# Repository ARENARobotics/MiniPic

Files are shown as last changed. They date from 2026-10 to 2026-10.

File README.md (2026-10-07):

# MiniPic: Benchtop Vacuum Tweezers

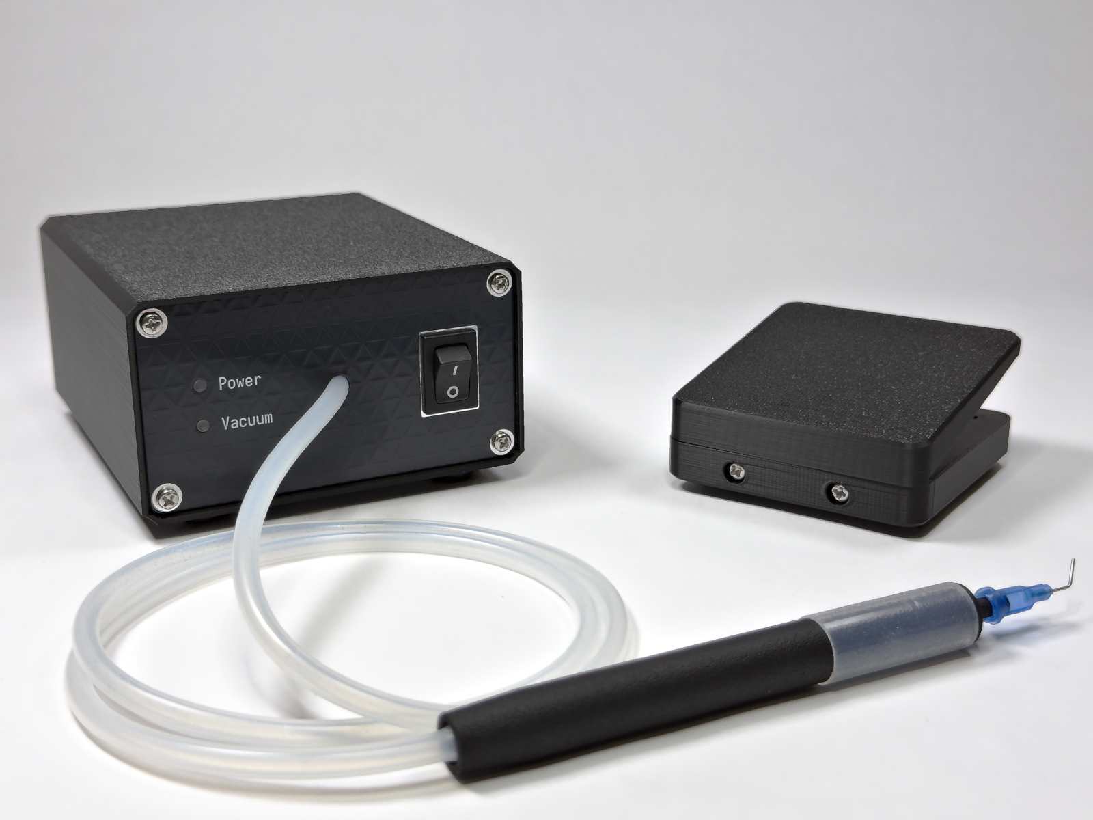
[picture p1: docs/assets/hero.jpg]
MiniPic Hero






Open-source vacuum tweezers built for repairability. Engineered for SMD soldering and precision rework, with a robust design adaptable to any application requiring controlled suction and handling of small parts.

---

### Features

* **Two operating modes:** foot pedal starts or stops the vacuum motor
* **Solenoid valve** for instant component release
* **Heat-resistant pen** rated up to **160°C**
* **Full set of precision needles and suction cups** for all sizes of SMD components
* Handles components down to **0201 (0.6 x 0.3mm)** and up to **100g**
* **Flexible silicone** vacuum tubing
* **MX hot-swap mechanical switch** in the foot pedal
* **Slip-resistant** rubber feet
* **Inline filter** to protect the vacuum motor
* **LED status indicator** for vacuum engagement

---

### Documentation & Source Files

* **[Assembly Manual](./docs/ASSEMBLY_MANUAL.pdf)** - Step-by-step kit assembly Instructions & quickstart guide
* **[BOM](./BOM.csv)** - Bill of materials including reference links for purchase
* **[Electronics Source](./electronics)** - KiCAD projects for PCBs
* **[CAD Exports](./cad/exports)** - CAD export files (step)
* **[CAD Source](./cad/source%20files)** - CAD source files (FreeCAD)

---

### Our Story

Last summer, we founded a company developing advanced electronics for robot combat competitions. We were inexperienced and didn’t understand the market so the project didn’t work out. Throughout the project, we spent a lot of time designing and assembling PCBs on a tight budget. Like many others, we found that tweezers were cumbersome tools for placing SMD components. The search for a better alternative led us to vacuum tweezers, tools designed to pick and place SMD components using controlled suction. The plan was to buy something off the shelf, but all of the products that were in our price range were not usable. On the other hand, the existing professional tools would have drained our bank account. We were stuck between cheap, low quality options and expensive industrial tools, most of which lacked all the features we were actually looking for.

Out of this frustration, one of our team members got to work, and in a few days, we had a functional tool that made assembly faster and easier than before. After using it ourselves, we realized we could provide a better alternative to others facing the same lack of options. Using our prototype as inspiration, we redesigned our vacuum tweezers from the ground up. Highly functional while still remaining simple and repairable.

See MiniPic in action at: [arenarobotics.store](https://arenarobotics.store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).

---

### Licensing

* **Hardware & CAD files (`/electronics`, `/cad`):** Licensed under [CERN-OHL-S-v2](LICENSE.md).
* **Documentation & Media (`/docs`):** Licensed under [CC BY-NC-ND 4.0](https://creativecommons.org/licenses/by-nc-nd/4.0/).
* **Branding & Trademarks:** "MiniPic" and "ARENA Robotics" are trademarks of ARENA Robotics LLC. All rights reserved.

--- 

*Designed & Built by ARENA Robotics.*

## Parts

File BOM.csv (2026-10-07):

Part Name | Supplier | Link | Notes | Quantity
Pen Body | JLC | https://jlc3dp.com/3d-printing-quote | Use STEP files from Github | 1
Pen Grip | Amazon | https://www.amazon.com/uxcell-Silicone-Flexible-Silicon-Transfer/dp/B07PNR73WW/ |  | 1
18g, 21g, 23g Needles | Amazon | https://www.amazon.com/Waltool-Dispensing-Assortment-Stainless-Applicator/dp/B0FK4SYRQT/ |  | 1
18g Metal Needles | Amazon | https://www.amazon.com/Pack-Blunt-Dispensing-Needles-8G-18G/dp/B07QS6TR4G/ |  | 1
Suction Cup 3mm | AliExpress | https://www.aliexpress.us/item/2251832630050891.html |  | 1
Suction Cup 5mm | AliExpress | https://www.aliexpress.us/item/2251832630050891.html |  | 1
Suction Cup 10mm | AliExpress | https://www.aliexpress.us/item/2251832630050891.html |  | 1
Silicone Tube | AliExpress | https://www.aliexpress.us/item/3256811498681916.html |  | 1
Aux Cable | AliExpress | https://www.aliexpress.us/item/3256812323425938.html |  | 1
Hinge | JLC | https://jlcmc.com/product/s/D04/DJRG/spring-butterfly-binge-taper-hole?k=DJRG-25&productModelNumber=DJRG-25 |  | 1
Vacuum Pump | AliExpress | https://www.adafruit.com/product/4699 |  | 1
Solenoid valve | Adafruit | https://www.adafruit.com/product/4663 |  | 1
Main PCB | JLC | https://jlcpcb.com/ | Use Gerber file from Github | 1
Back Panel | JLC | https://jlcpcb.com/ | Use Gerber file from Github | 1
Front Panel | JLC | https://jlcpcb.com/ | Use Gerber file from Github | 1
Power Switch | Digikey | https://www.digikey.com/en/products/detail/e-switch/RA11131121/2720267 |  | 1
Rubber Feet | Digikey | https://www.digikey.com/en/products/detail/keystone-electronics/720/61956 |  | 8
Screws | JLC | https://www.amazon.com/Phillips-Tapping-Screws-Stainless-Steel/dp/B0825N1L3Z/ |  | 39
Vibration dampaning | JLC | https://jlcmc.com/product/s/H02/HJDQ/cushioning-strip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 |  | 1
Electrical Components | Digikey | Custom | Can be found in KiCAD files | 1
Spring | JLC | https://jlcmc.com/product/s/A04/ATJS/compression-springs-outer-diameter-reference-l%C3%97(35~40)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 |  | 1
Keyswitch | Amazon | https://www.amazon.com/GATERON-Switches-Pre-lubed-Mechanical-Keyboard/dp/B0DRF928W5 |  | 1
Keyswitch Socket | Adafruit | https://www.adafruit.com/product/4958 |  | 1
Filter | AliExpress | https://www.aliexpress.us/item/3256812076290057.html |  | 1

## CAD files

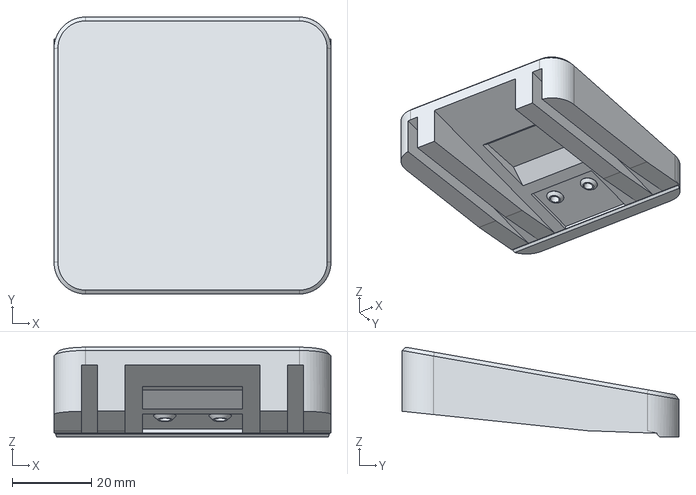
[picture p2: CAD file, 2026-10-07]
cad/exports/Foot Pedal - Top.step
70.0 x 70.0 x 22.6 mm

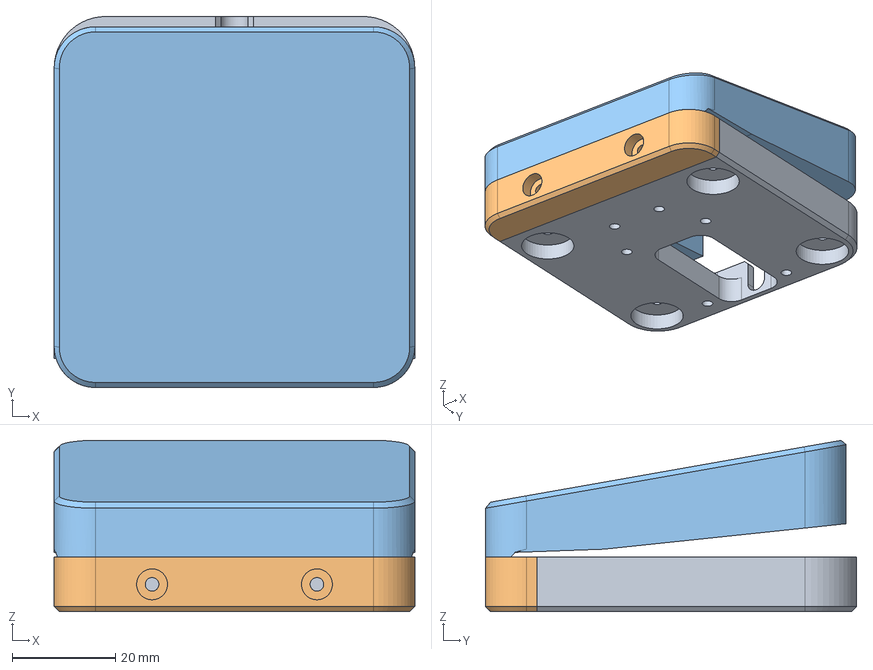
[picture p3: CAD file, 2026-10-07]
cad/source files/Foot Pedal.FCStd
70.0 x 72.0 x 33.2 mm
Base
Front
Top

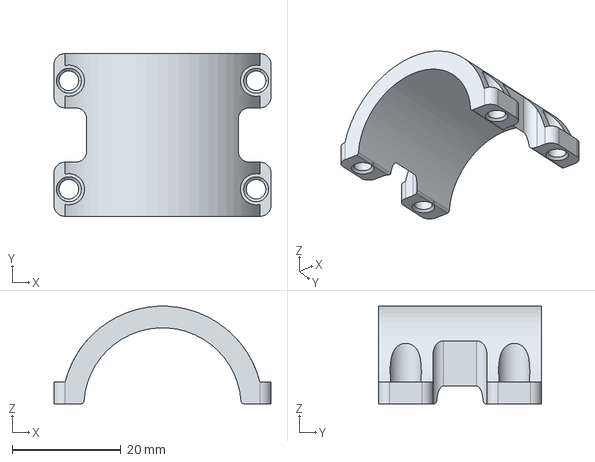
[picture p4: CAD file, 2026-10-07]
cad/exports/Base Station - Vacuum Cover.step
40.0 x 30.0 x 18.0 mm

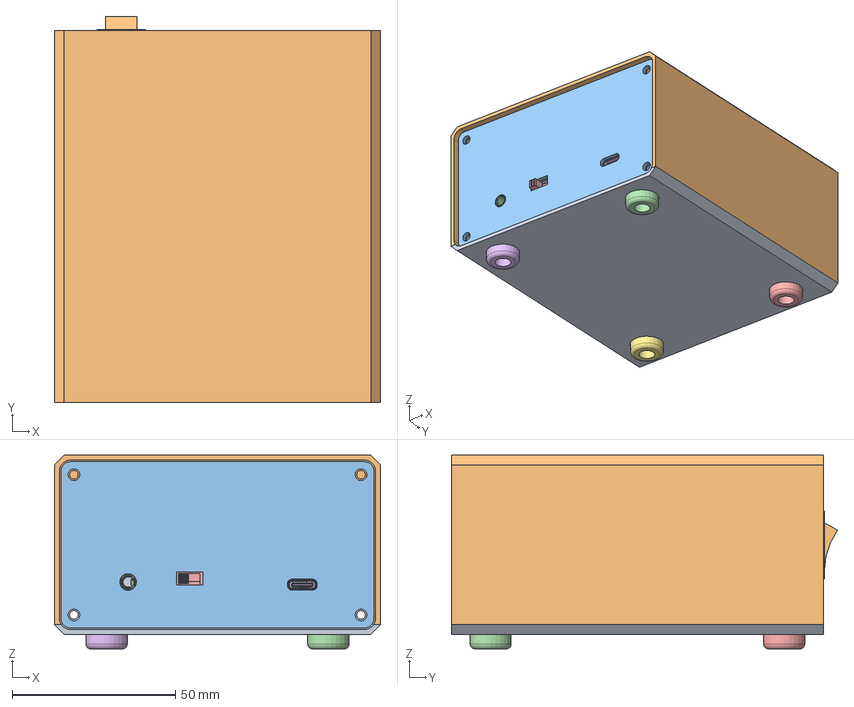
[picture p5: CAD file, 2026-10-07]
cad/source files/Base Station.FCStd
100.0 x 118.3 x 59.4 mm
Base
Cover
Back PCB
Foot 720 #001 x 2
Foot 720 #002 x 2
Foot 720 #003 x 2
Foot 720 #004 x 2
Vacuum Cover
Vacuum Motor v1
Power Switch001
Front Plate v0.1.0
Solenoid
Vaccum Tweezers_LED_holder_silkscreen
Vaccum Tweezers_LED_holder_PCB
LED Separator
Solenoid Cover
Light Pipe
Filter
Filter Cover
CUI_DEVICES_SJ-3523-SMT-TR001
Same_Sky_SLW-158562-5A-RA-N-D001
10164359-00011LF
Vaccum Tweezers_PCB

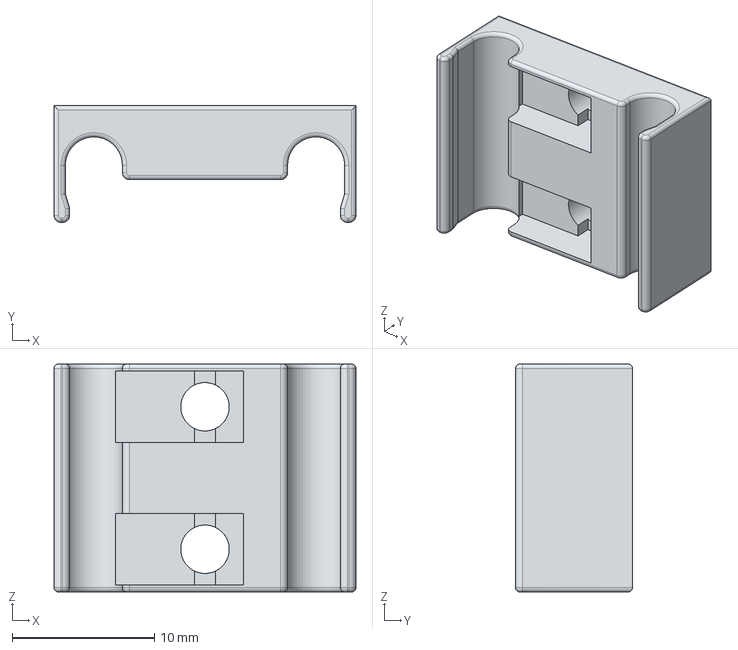
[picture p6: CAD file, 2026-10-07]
cad/exports/Base Station - LED Separator.step
21.2 x 8.20 x 16.0 mm

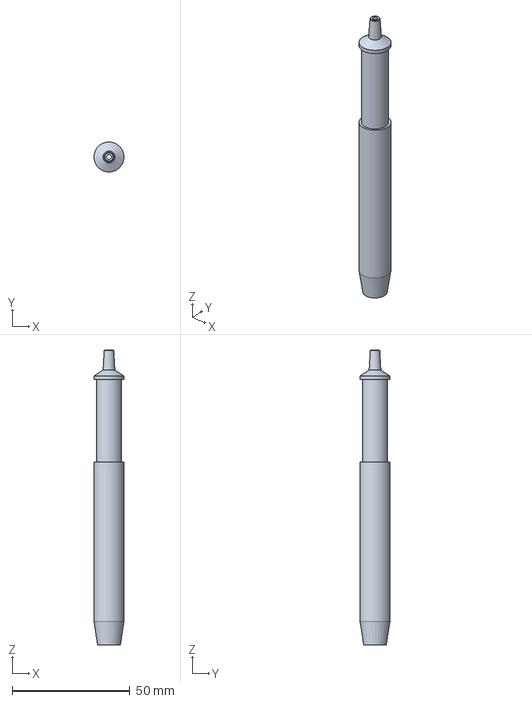
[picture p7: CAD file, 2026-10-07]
cad/source files/Pen.FCStd
12.7 x 12.7 x 125.0 mm

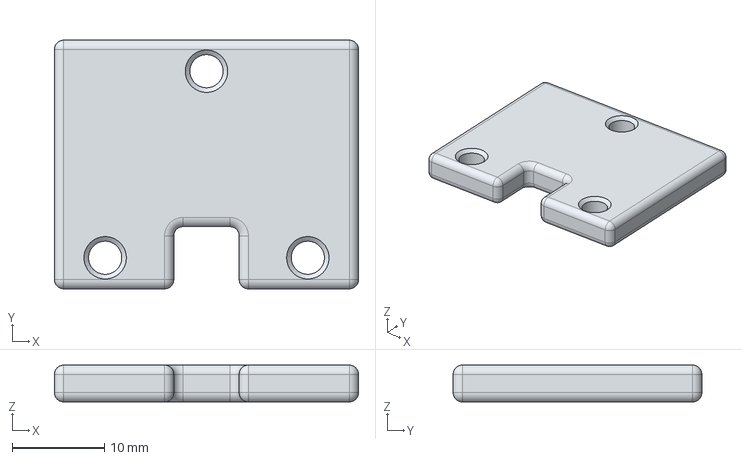
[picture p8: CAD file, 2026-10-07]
cad/exports/Base Station - Solenoid Cover.step
33.0 x 27.0 x 4.00 mm

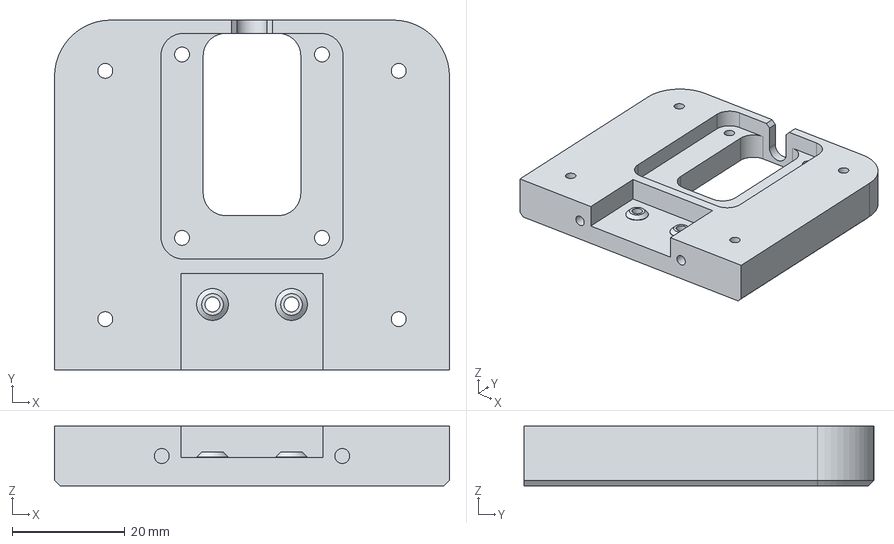
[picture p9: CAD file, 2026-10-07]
cad/exports/Foot Pedal - Base.step
70.0 x 62.0 x 10.6 mm

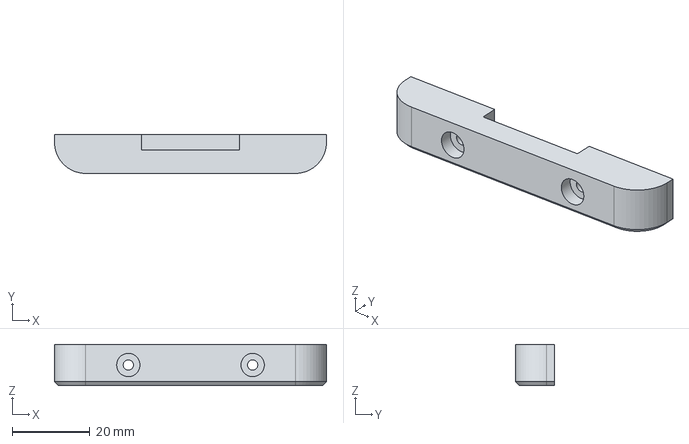
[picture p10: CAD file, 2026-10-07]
cad/exports/Foot Pedal - Front.step
70.0 x 10.0 x 10.6 mm

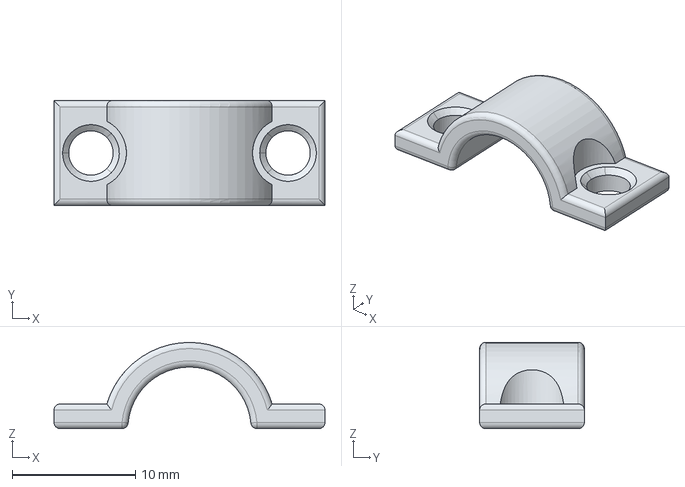
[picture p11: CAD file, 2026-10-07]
cad/exports/Base Station - Filter Cover.step
22.0 x 8.50 x 7.00 mm

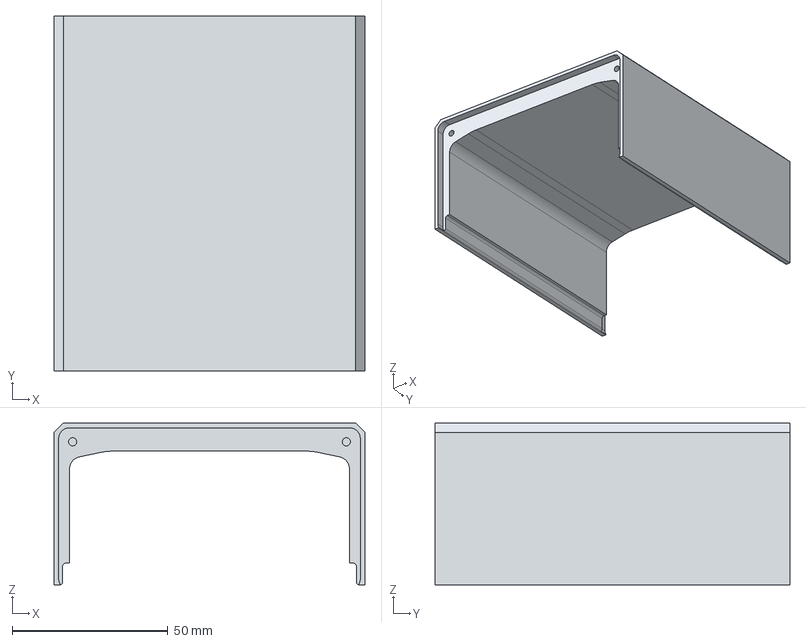
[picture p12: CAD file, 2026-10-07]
cad/exports/Base Station - Lid.step
100.0 x 114.0 x 52.0 mm

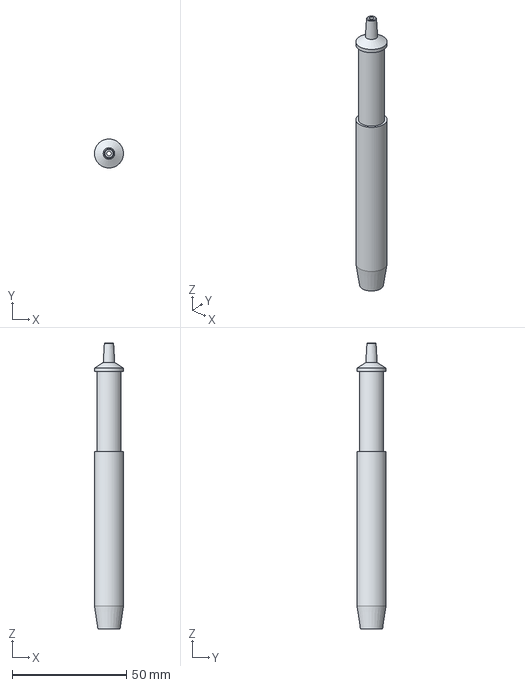
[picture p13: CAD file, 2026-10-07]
cad/exports/Pen - Body.step
12.7 x 12.7 x 125.0 mm

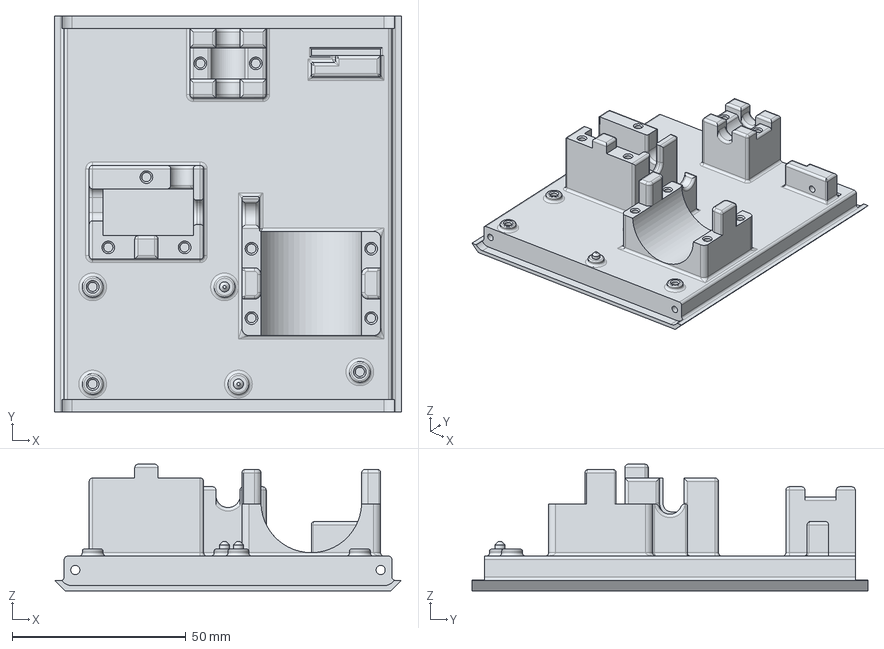
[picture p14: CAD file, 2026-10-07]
cad/exports/Base Station - Base.step
100.0 x 114.0 x 36.5 mm

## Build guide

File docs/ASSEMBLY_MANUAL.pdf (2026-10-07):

# ARENA Robotics

## MiniPic: Benchtop Vacuum Tweezers

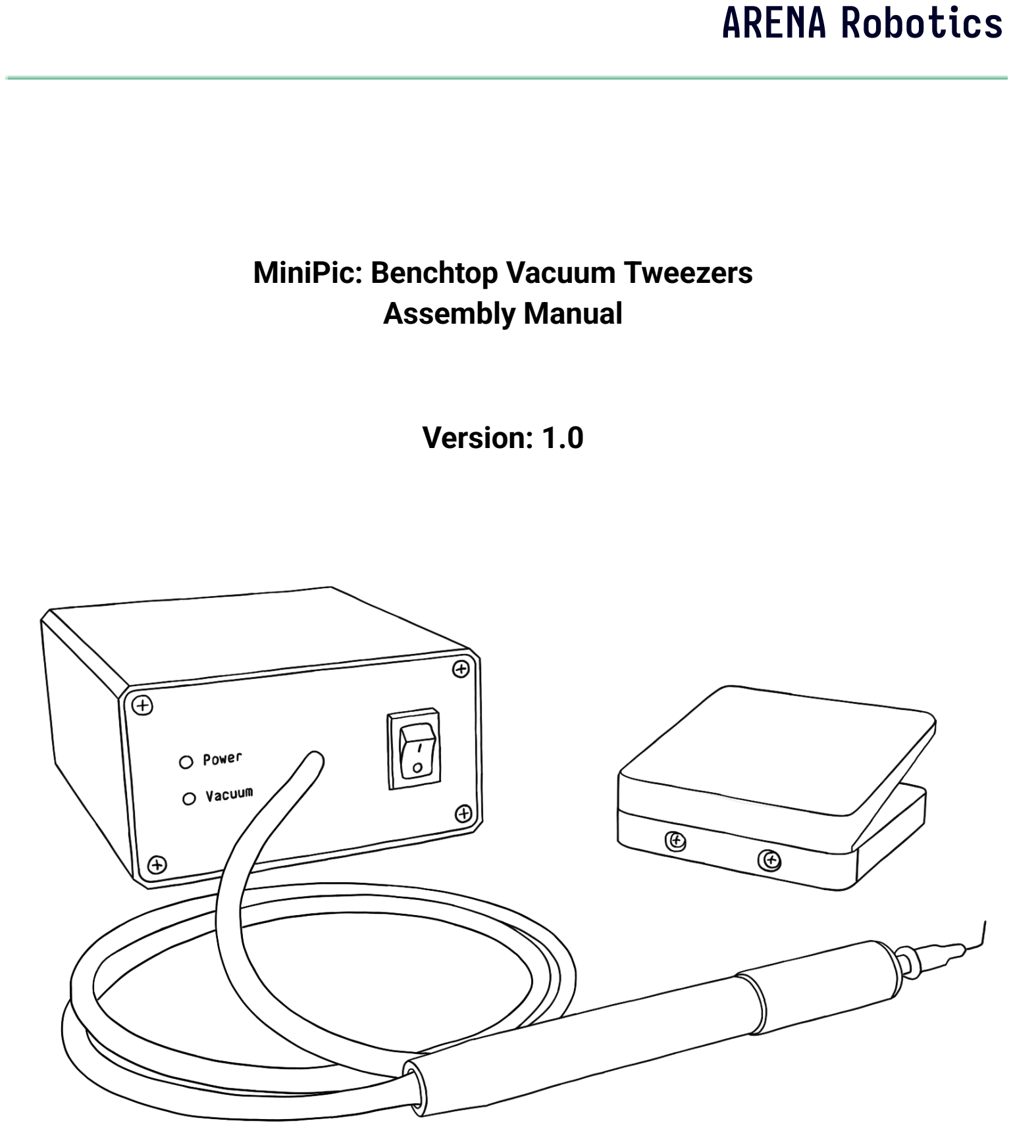
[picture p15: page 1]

## Assembly Manual

## Version: 1.0

# Table of Contents

MiniPic: Benchtop Vacuum Tweezers | 2 of 14

# Quickstart Guide

The foot pedal can be configured to be normally open (NO), meaning that the vacuum only activates when the pedal is pressed. If the device is switched into normally closed (NC) mode, then the vacuum will be on unless interrupted by the foot pedal. Feel free to try both modes and find what works best for you.

There are two LEDs on the front panel of the MiniPic. The green “Power” LED lights up whenever USB-C power and the power switch is turned on. The blue “Vacuum” LED lights up whenever the vacuum motor and solenoid are activated.

All source files, 3D models, and a bill of materials can be found on GitHub at: https://github.com/ARENARobotics/MiniPic

MiniPic: Benchtop Vacuum Tweezers | 3 of 14

## What’s in the Box

### Main Unit

➔ Main PCB | ( x1)
➔ LED Holder | ( x1)
➔ LED Cable | ( x1)
➔ Power Switch | ( x1)
➔ Power Cable | ( x1)
➔ Vacuum Motor | ( x1)
➔ Solenoid | ( x1)
➔ Filter | ( x1)
➔ Rubber Foot | ( x4)
➔ Pen Body | ( x1)
➔ Box of Pen Tips | ( x1)
➔ USB-C Cable | ( x1)
➔ Screws | (x25)
➔ 20mm Tube | ( x1)
➔ 40mm Tube | ( x1)
➔ 3m Tube | ( x1)
➔ Front Plate | ( x1)
➔ Back Plate | ( x1)
➔ Base | ( x1)
➔ Lid | ( x1)
➔ Vacuum Cover | ( x1)
➔ Solenoid Cover | ( x1)
➔ Filter Cover | ( x1)

### Foot Pedal

➔ Pedal PCB | ( x1)
➔ Key Switch | ( x1)
➔ Hinge | ( x1)
➔ Aux Cord | ( x1)
➔ Rubber Foot | ( x4)
➔ Screws | (x14)
➔ Pedal Base | ( x1)
➔ Pedal Top | ( x1)
➔ Front Bumper | ( x1)
MiniPic: Benchtop Vacuum Tweezers | 4 of 14

# Main Unit Assembly:

## Note

Parts shown in this manual may appear differently than what was shipped. Any differences are cosmetic, or in any case will not affect the assembly of the device.

## STEP 1: Plug 40mm Tube onto Solenoid and Filter

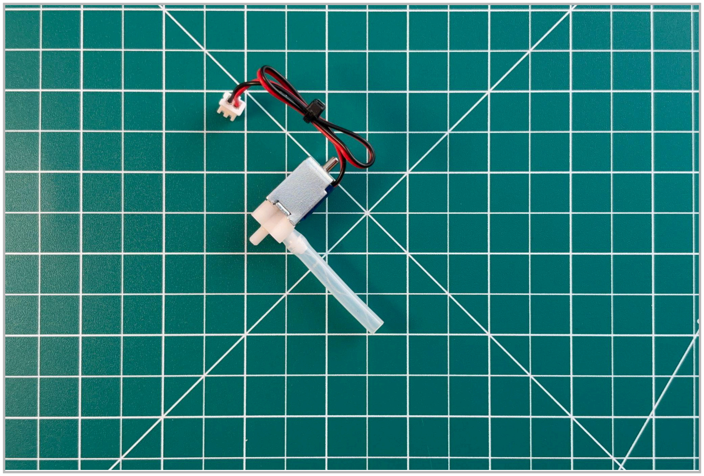
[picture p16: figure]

➔ 40mm Tube must be connected to the side port of the Solenoid ➔ 40mm Tube can connect to either port of the Filter

## STEP 2: Plug 20mm Tube onto Solenoid and Vacuum Motor

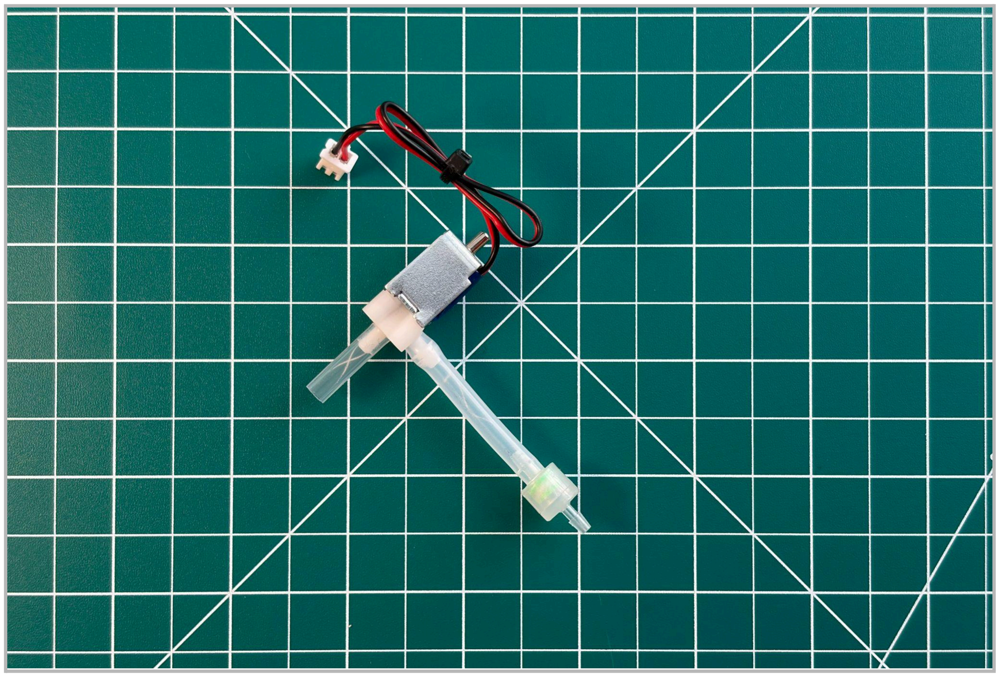
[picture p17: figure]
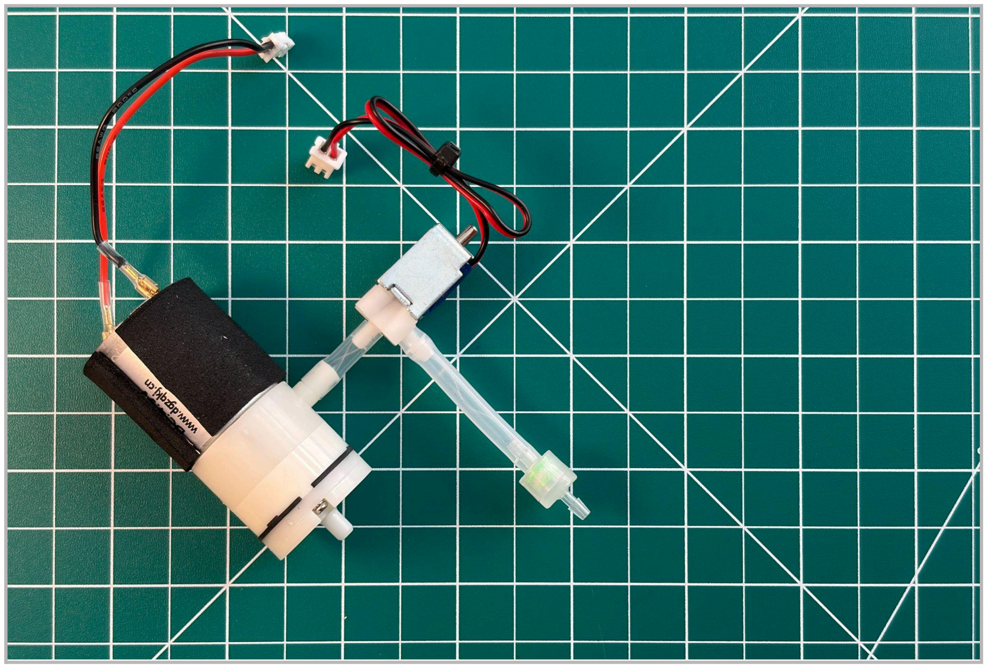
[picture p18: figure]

➔ 20mm Tube must be connected to the Solenoid port opposite its cable
➔ 20mm Tube must be connected to the side port of the Vacuum Motor
➔ 20mm Tube must be fully compressed against the ends of the ports on the Solenoid and Vacuum Motor
MiniPic: Benchtop Vacuum Tweezers | 5 of 14

## STEP 3: Install Solenoid, Vacuum Motor, and Filter

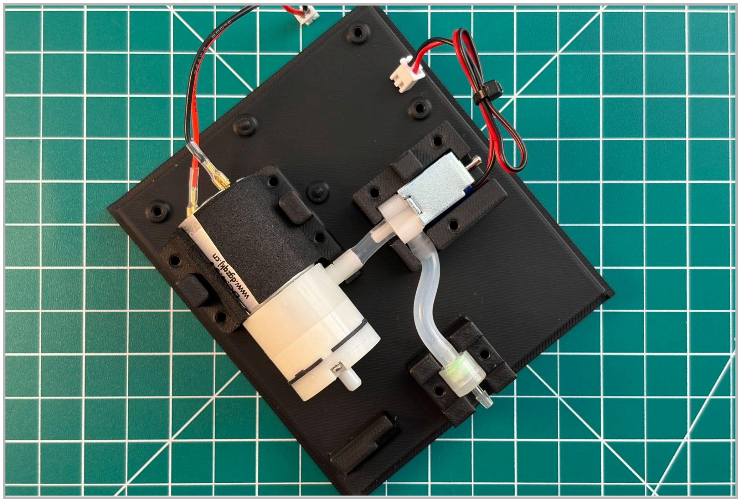
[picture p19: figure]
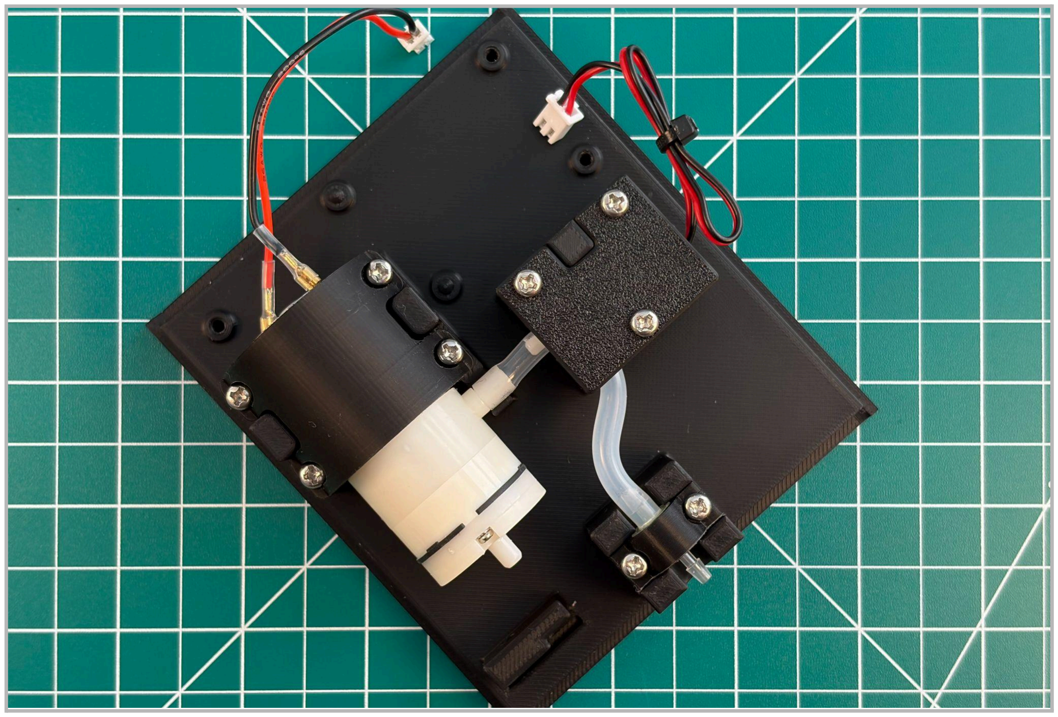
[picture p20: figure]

➔ Screw in all covers using included screws

⚠ A 1mm gap should be maintained between the Vacuum Cover and the Base so that the foam on the vacuum motor is not over compressed

## STEP 4: Install Main PCB

➔ Screw in using included screws

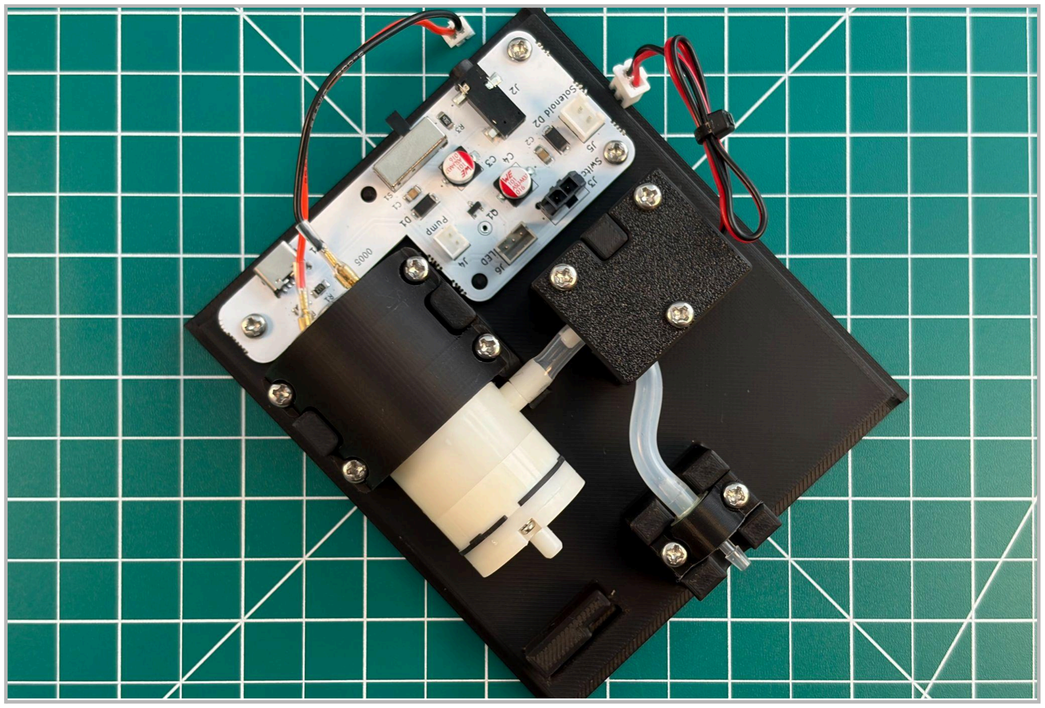
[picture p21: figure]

## STEP 5: Plug in Vacuum Motor and Solenoid

➔ Plug Solenoid into Main PCB
➔ Plug Vacuum Motor into Main PCB
MiniPic: Benchtop Vacuum Tweezers | 6 of 14

Note orientation of plugs,
each can only be inserted in one orientation

## STEP 6: Attach LED Cable

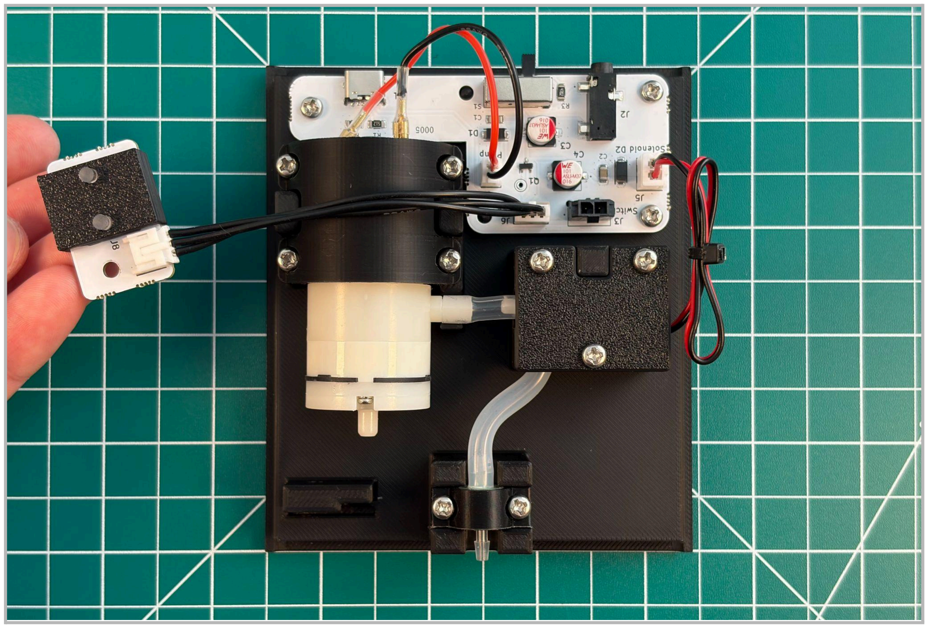
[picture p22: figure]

➔ Plug LED Cable into LED Holder, then Main PCB

Note orientation of plugs, each can only be inserted in one orientation

## STEP 7: Install LED Holder

➔ PCB must be fully seated in the Base

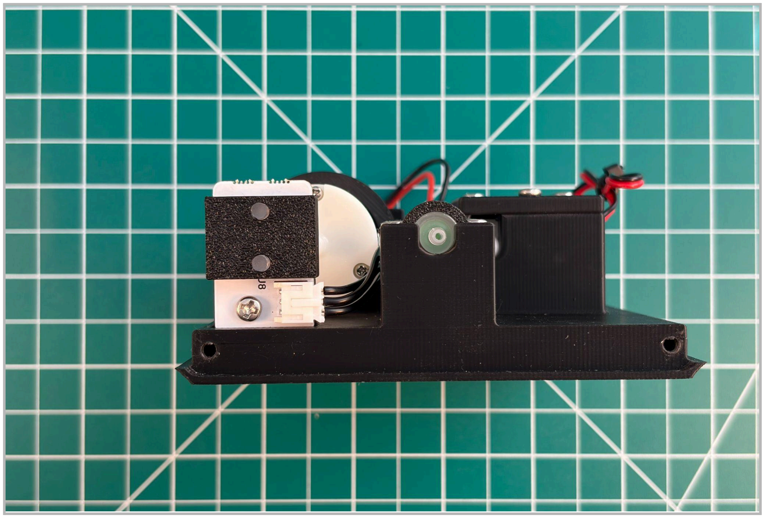
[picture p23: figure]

## STEP 8: Install Power Switch

➔ Snap Power Switch into Front Plate until the border of the switch is flush against the Front Plate
➔ Note orientation of the Power Switch relative to the Front Plate
MiniPic: Benchtop Vacuum Tweezers | 7 of 14

## STEP 9: Attach Power Cable

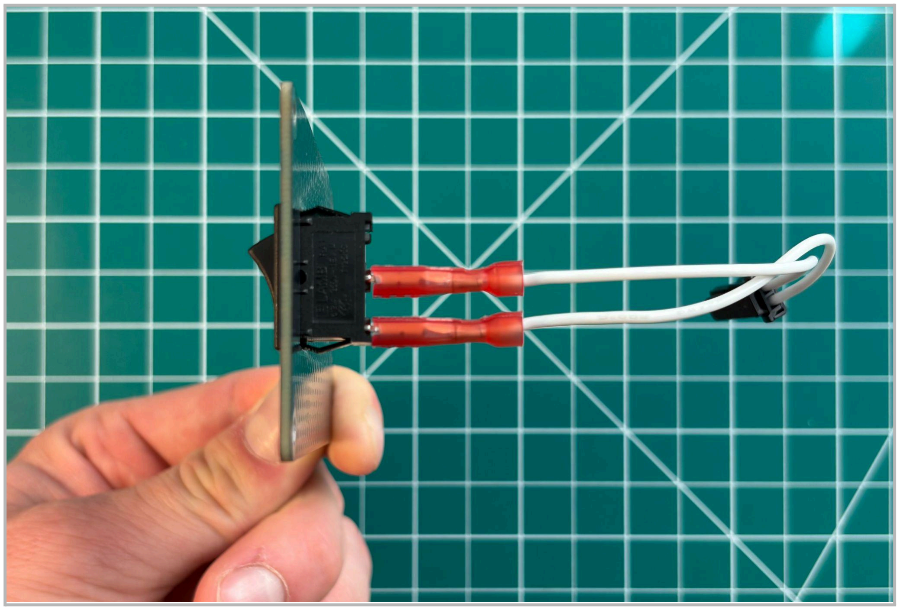
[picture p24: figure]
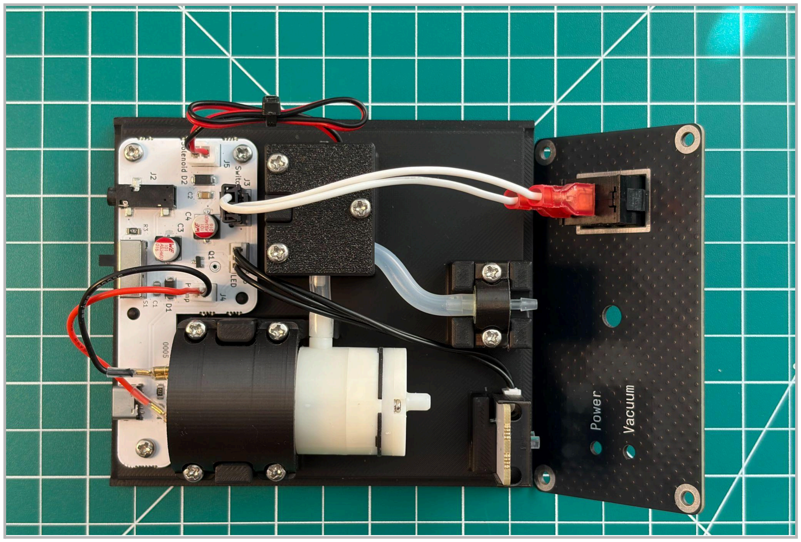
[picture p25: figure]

➔ Plug red contacts onto the terminals on the Power Switch. Orientation and placement do not matter.

➔ Plug the connector on the opposite end of the cable into the Main PCB

Note orientation of the connector that plugs into the Main PCB. The connector can only be inserted in one orientation.

## STEP 10: Install Front and Back Panels

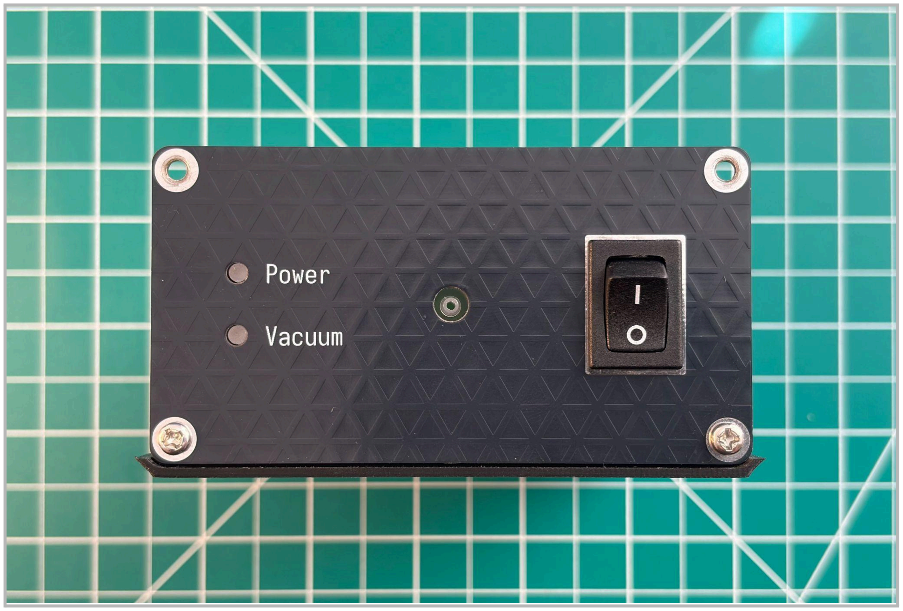
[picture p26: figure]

➔ Screw in Front Panel and Back Panel with included screws

MiniPic: Benchtop Vacuum Tweezers | 8 of 14

## STEP 11: Install Lid

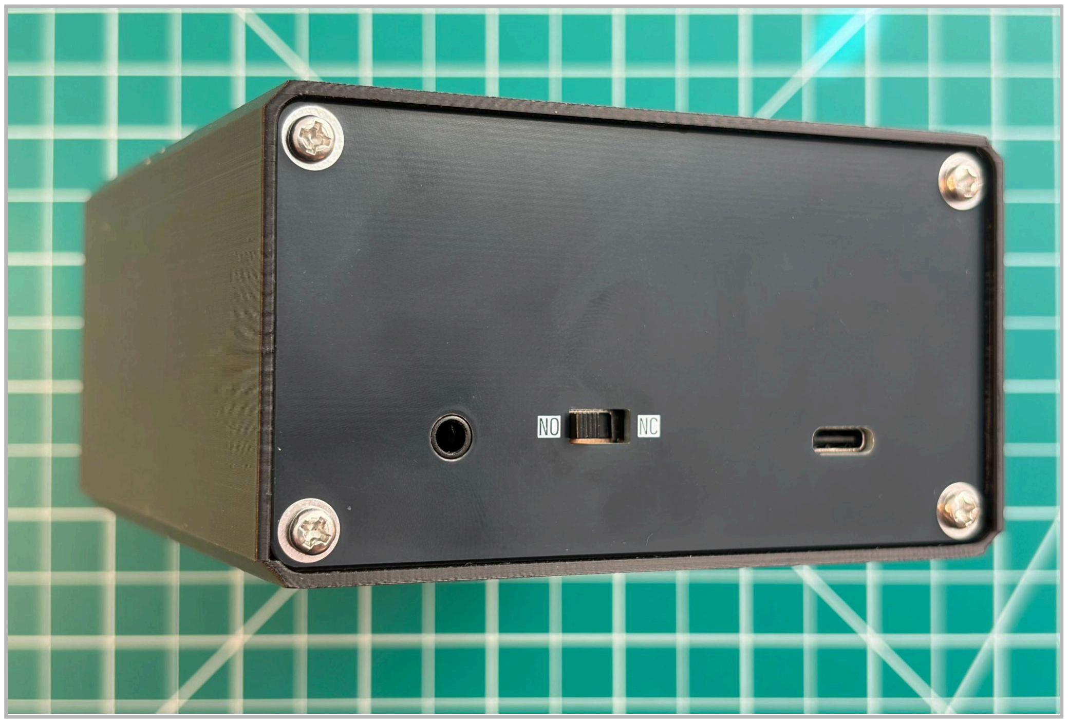
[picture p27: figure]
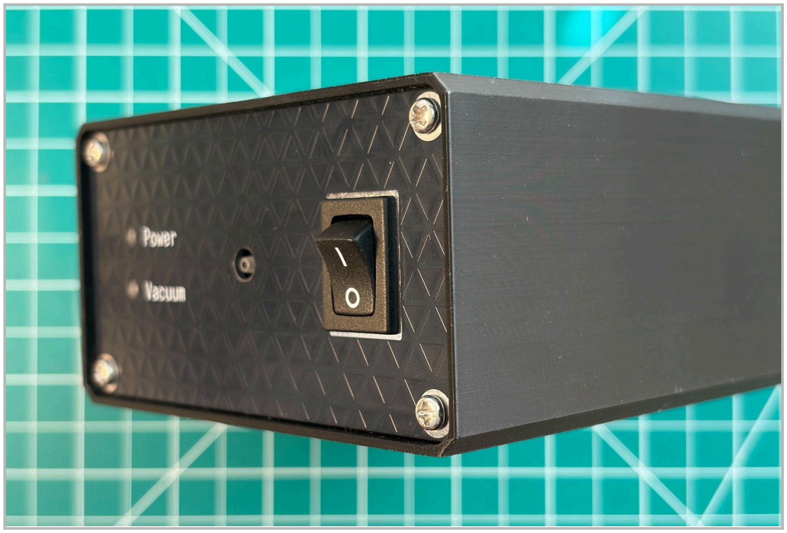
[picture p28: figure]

➔ Lower Lid onto Base, and then install using included screws

⚠

Ensure that wires are not pinched when closing the lid! Pinched cables can get damaged and cause unexpected behavior!

## STEP 12: Install feet

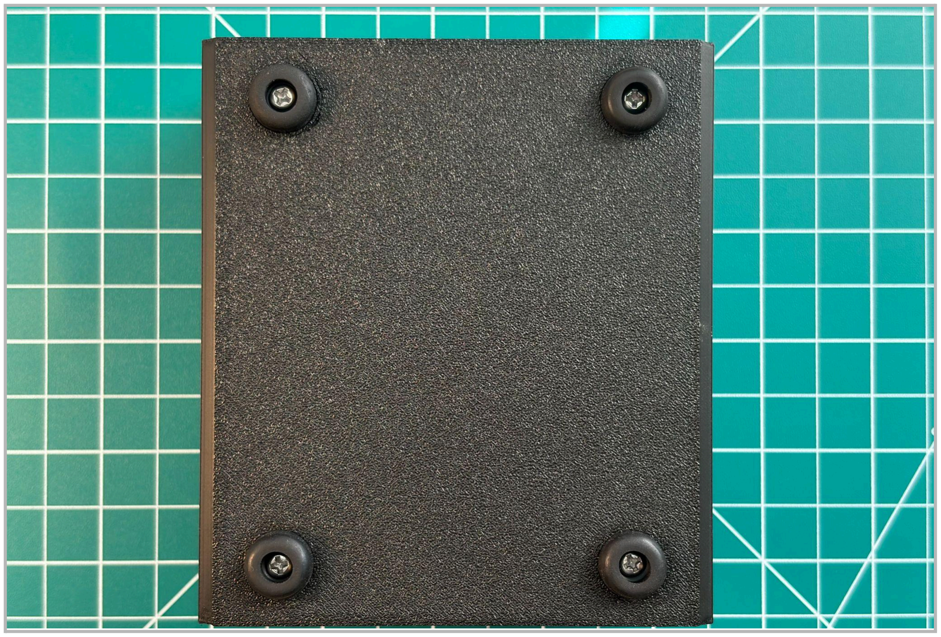
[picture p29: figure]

➔ Screw in feet using included screws

MiniPic: Benchtop Vacuum Tweezers | 9 of 14

## STEP 13: Attach Pen

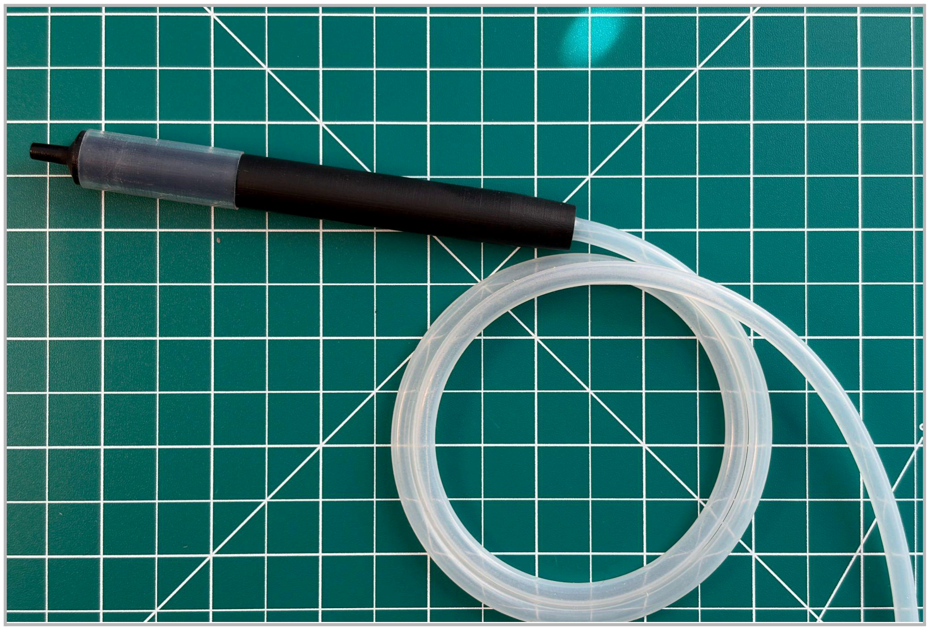
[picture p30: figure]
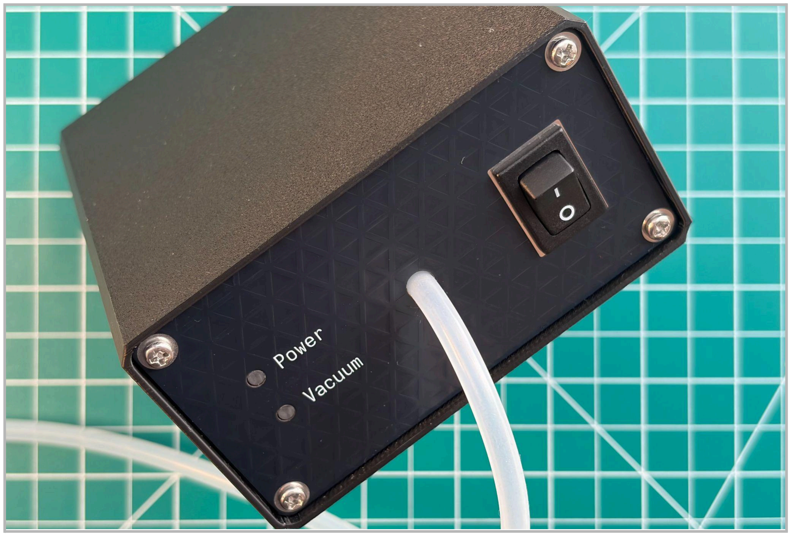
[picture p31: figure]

➔ Plug 3m Tube into Pen Body, then into Main Unit

## STEP 14: Attach Pen Tip

➔ Press a Pen Tip onto end of Pen Body

➔ A variety of needle tips are included for use with different size components. Larger needle gauges generally work better for larger components.
➔ Multiple suction cups are included for use with heavy components. To use a suction cup, simply press one onto the end of a needle tip. The suctions cups work best on the 18 gauge all metal tip and the 18 gauge green tip.
⚠ Plastic pen tips can crack over time if too much force is used to press them onto the pen body. We recommend inserting them lightly, and then pressing harder if the vacuum is too weak.
MiniPic: Benchtop Vacuum Tweezers | 10 of 14

## STEP 15: Test out the Main Unit!

Once plugged into a USB power source, the pen can be operated using just the power switch on the front or the slide switch on the back. The vacuum pump should turn on once the device is powered on. If no suction can be felt at the pen tip, review all tubing and electrical connections.

MiniPic: Benchtop Vacuum Tweezers | 11 of 14

# Foot Pedal Assembly

## Note

Parts shown in this manual may appear differently than what was shipped. Any differences are cosmetic, or in any case will not affect the assembly of the device.

## STEP 1: Install Pedal PCB

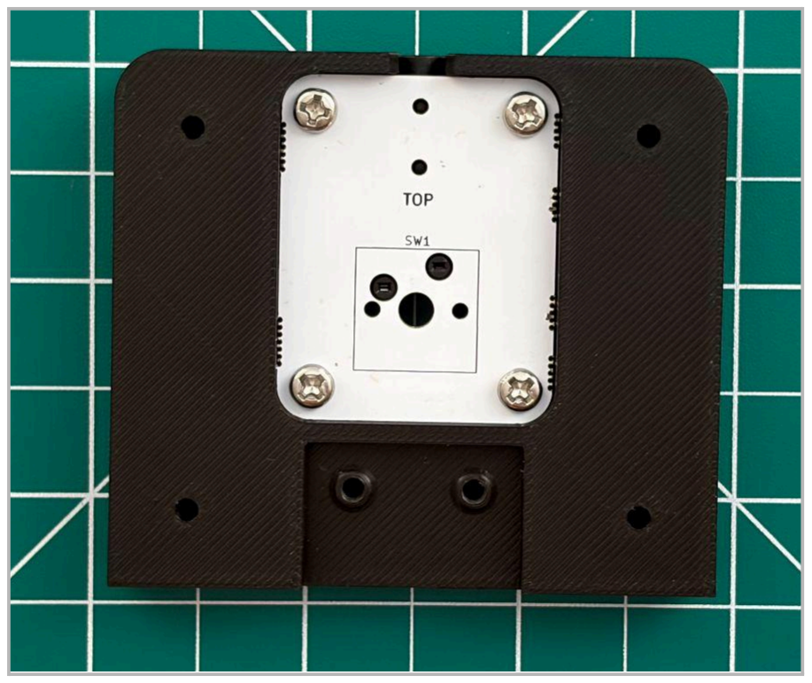
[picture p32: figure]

➔ Note: the labels on the Pedal PCB should go on the corresponding face of the Pedal Base. Feet screw into the bottom face orientation of Pedal Base.

## STEP 2: Insert Key Switch

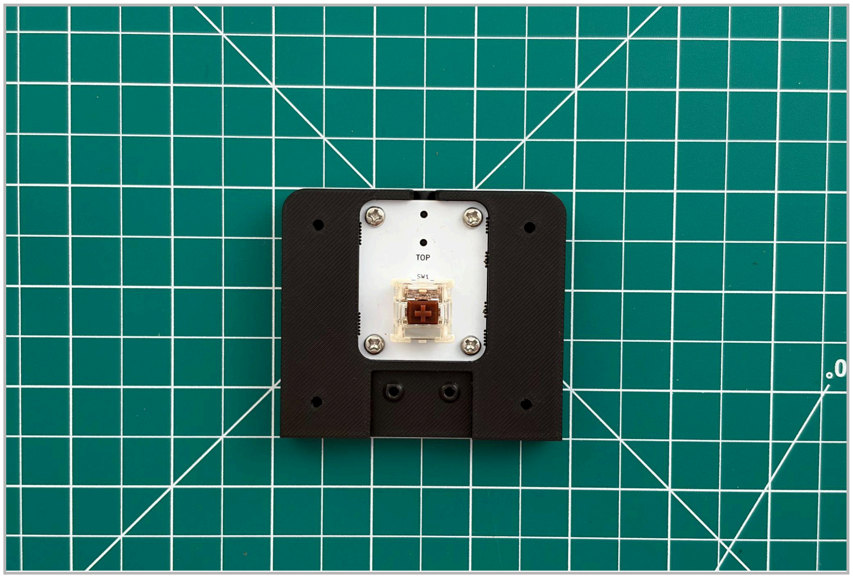
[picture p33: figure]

➔ Press Key Switch into Pedal PCB

MiniPic: Benchtop Vacuum Tweezers | 12 of 14

⚠ Use alignment posts on Key Switch to ensure the metal terminals do not bend

## STEP 3: Install Hinge

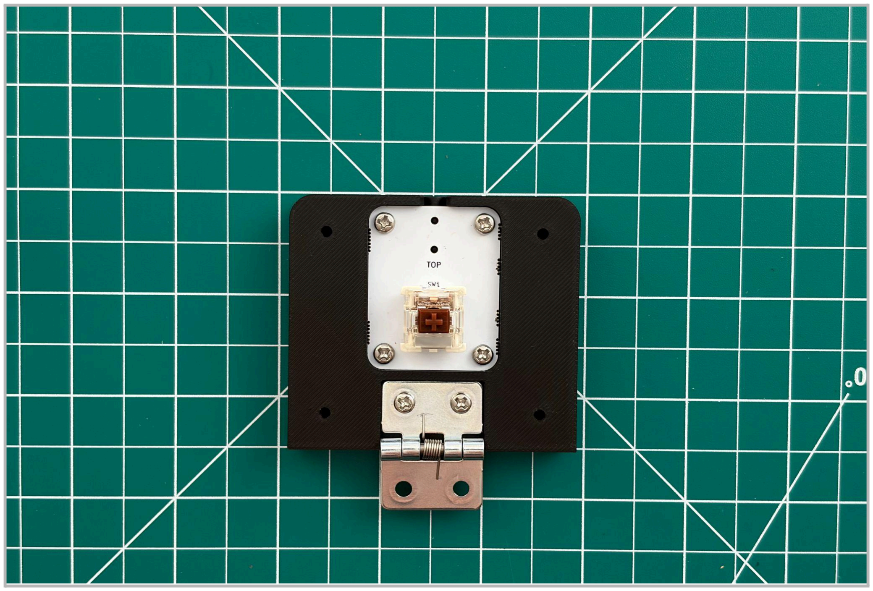
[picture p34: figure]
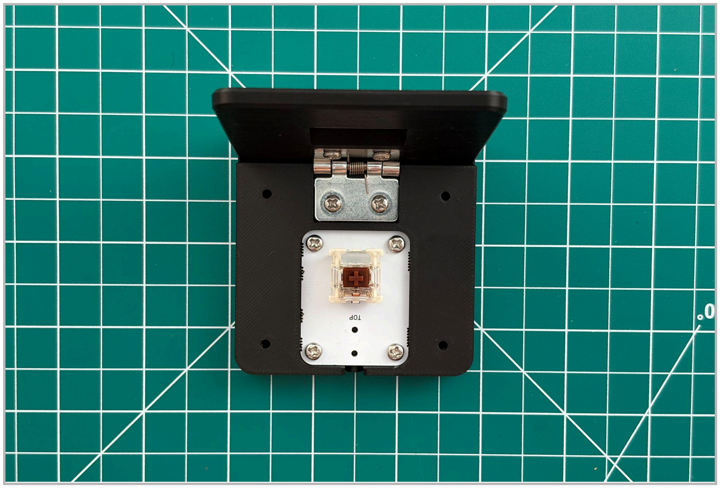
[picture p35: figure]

➔ Screw into Pedal Base and then Pedal Top

## STEP 4: Install Front Bumper

➔ Pedal Top must be pressed against the Pedal Base
➔ Screws installed in this step can strip easily, so tighten slowly

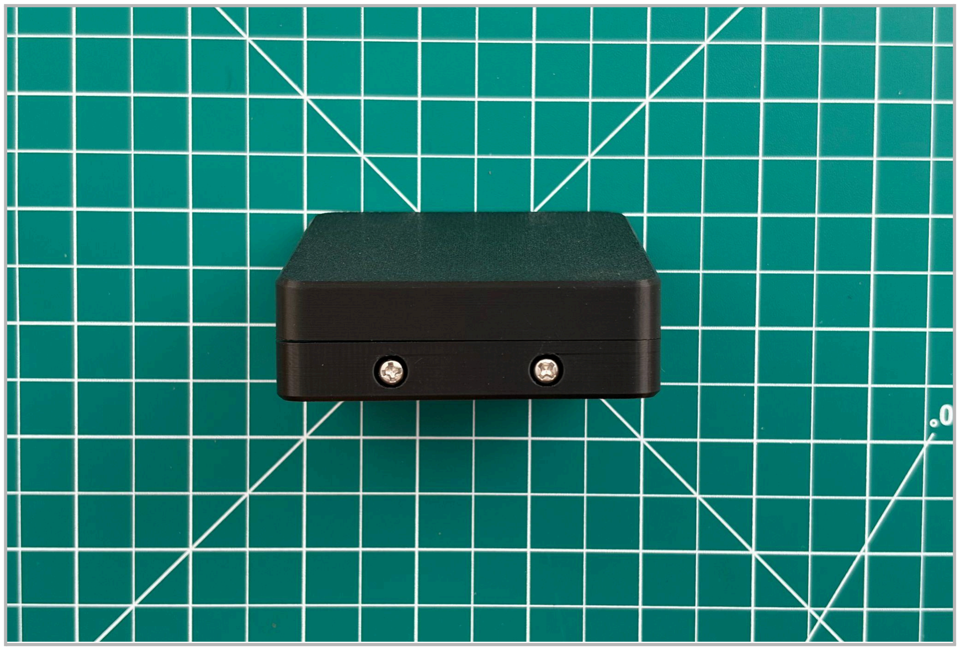
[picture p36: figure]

## STEP 5: Install Feet

➔ Install using included screws

MiniPic: Benchtop Vacuum Tweezers | 13 of 14

## STEP 6: Plug in Aux Cord

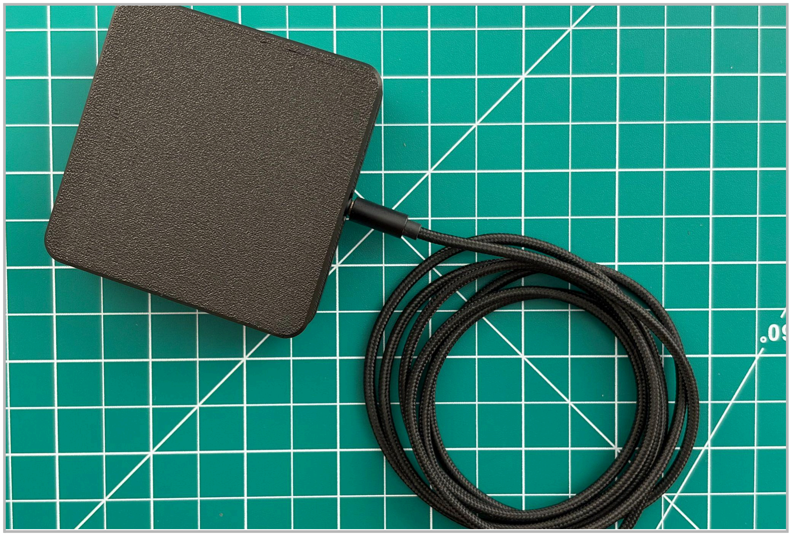
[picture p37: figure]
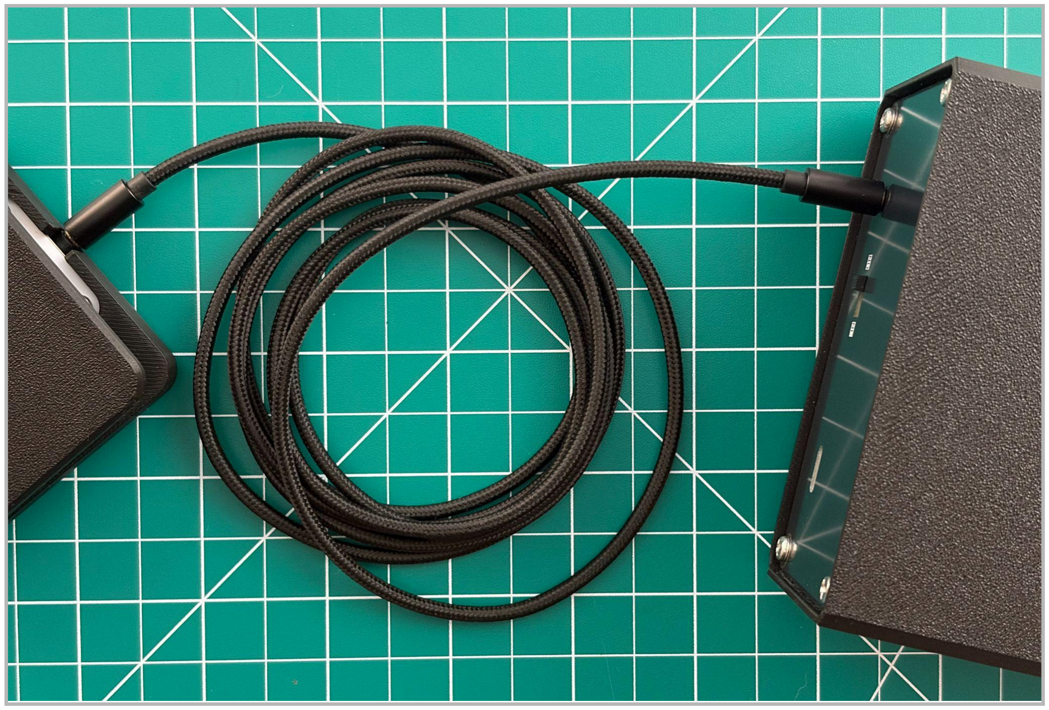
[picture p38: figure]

➔ Insert each connector until almost no brass is visible on the connector

## STEP 7: Start Building!

With the foot pedal attached, your MiniPic is now fully assembled! The foot pedal can be configured to be normally open (NO), meaning that the vacuum only activates when the pedal is pressed. If the device is switched into normally closed (NC) mode, then the vacuum will be on unless interrupted by the foot pedal. Feel free to try both modes and find what works best for you.

MiniPic: Benchtop Vacuum Tweezers | 14 of 14

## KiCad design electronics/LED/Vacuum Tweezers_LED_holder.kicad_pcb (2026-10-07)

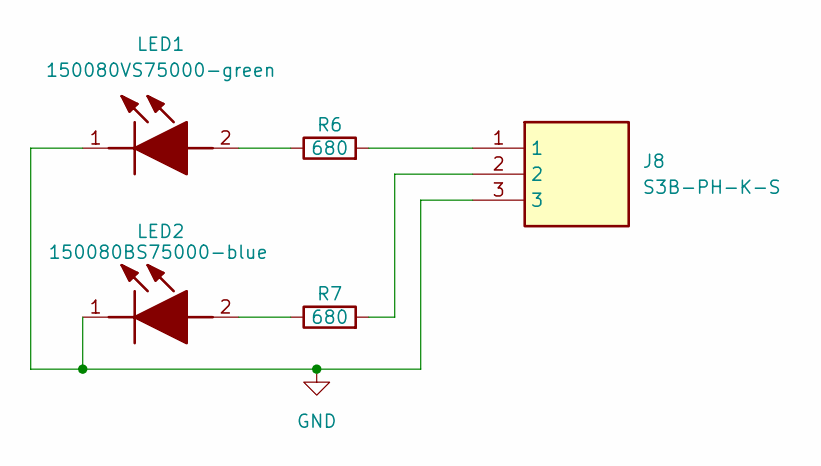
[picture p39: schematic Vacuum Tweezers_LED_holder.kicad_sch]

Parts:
J8: S3B-PH-K-S; S3BPHKS; Manufacturer_Part_Number S3B-PH-K-S
LED1: 150080VS75000-green; LEDC2012X70N; Manufacturer_Part_Number 150080VS75000; Mouser Part Number 710-150080VS75000
LED2: 150080BS75000-blue; LEDC2012X70N; Manufacturer_Part_Number 150080BS75000; Mouser Part Number 710-150080BS75000
R6, R7: 680; R_0805_2012Metric

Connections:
GND: J8.3, LED1.1 (K), LED2.1 (K)
unnamed: J8.1, R6.2
unnamed: J8.2, R7.2
unnamed: LED1.2 (A), R6.1
unnamed: LED2.2 (A), R7.1

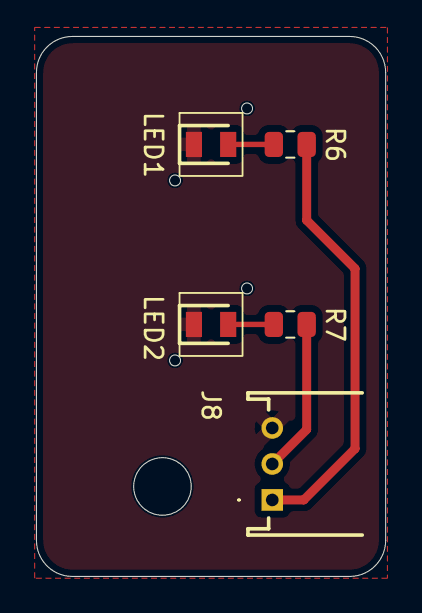
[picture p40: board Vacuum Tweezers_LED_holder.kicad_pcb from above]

Board: 2 copper layers, 19.4 x 30.0 mm, 5 parts (0 on the bottom side), 5 nets.

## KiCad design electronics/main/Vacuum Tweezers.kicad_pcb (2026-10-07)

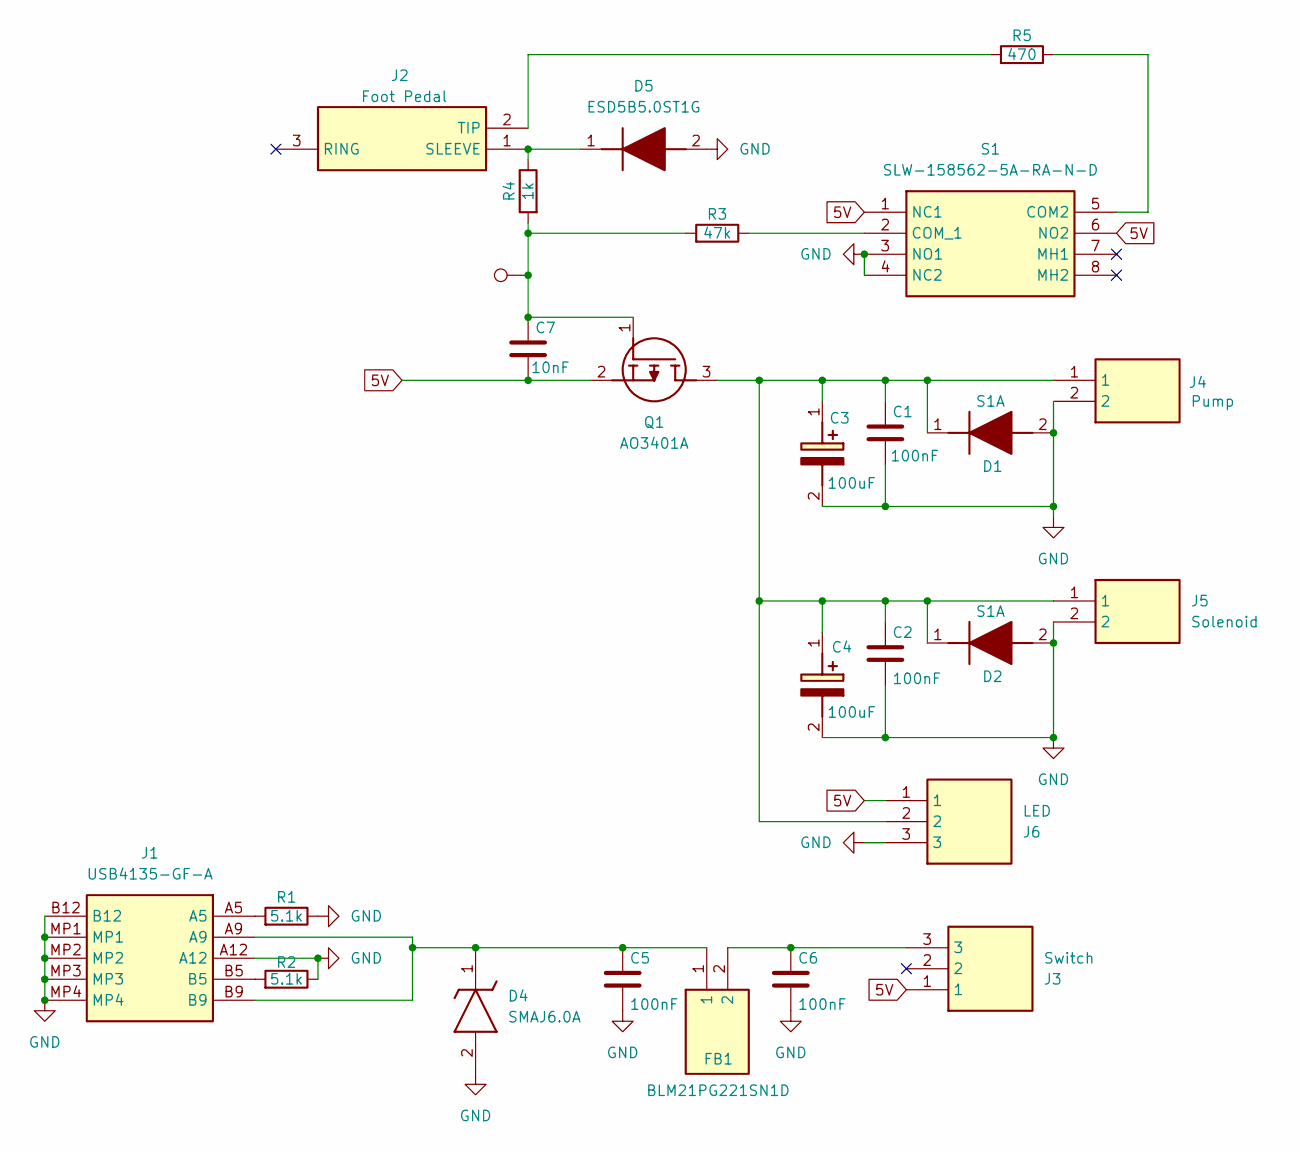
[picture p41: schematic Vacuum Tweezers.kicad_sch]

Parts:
C1, C2, C5, C6: 100nF; C_0805_2012Metric
C3, C4: 100uF; 865080343009; Manufacturer_Part_Number 865080343009; Mouser Part Number 710-865080343009
C7: 10nF; C_0805_2012Metric
D1, D2: S1A; DIOM5127X261N; Manufacturer_Part_Number S1A
D4: SMAJ6.0A; DIOM6626X229N; Manufacturer_Part_Number SMAJ6.0A; Mouser Part Number 576-SMAJ6.0A
D5: ESD5B5.0ST1G; SODFL1608X70N; Manufacturer_Part_Number ESD5B5.0ST1G; Mouser Part Number 863-ESD5B50ST1G
FB1: BLM21PG221SN1D; BEADC2012X105N; Manufacturer_Part_Number BLM21PG221SN1D; Mouser Part Number 81-BLM21P221SG
J1: USB4135-GF-A; USB4135GFA; Manufacturer_Part_Number USB4135-GF-A; Mouser Part Number 640-USB4135-GF-A
J2: Foot Pedal; SJ3523SMTTR; Manufacturer_Part_Number SJ-3523-SMT-TR; Mouser Part Number 490-SJ-3523-SMT-TR
J3: Switch; B3BXHALFSN; Manufacturer_Part_Number B3B-XH-A(LF)(SN); Mouser Part Number 306-B3BXHALFSNP
J4: Pump; B2BPHKS; Manufacturer_Part_Number B2B-PH-K-S
J5: Solenoid; B2BXHAGU; Manufacturer_Part_Number B2B-XH-A-GU; Mouser Part Number N/A
J6: LED; B3BPHKLLFSN; Manufacturer_Part_Number B3B-PH-KL (LF)(SN)
Q1: AO3401A; SOT95P280X125-3N; Manufacturer_Part_Number AO3401A
R1, R2: 5.1k; R_0805_2012Metric
R3: 47k; R_0805_2012Metric
R4: 1k; R_0805_2012Metric
R5: 470; R_0805_2012Metric
S1: SLW-158562-5A-RA-N-D; SW_SLW-158562-5A-RA-N-D; Manufacturer_Part_Number SLW-158562-5A-RA-N-D; Mouser Part Number 179-SLW1585625ARAND
TP1: TestPoint; TestPoint_Keystone_5000-5004_Miniature

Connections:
5V: C7.2, J3.1, J6.1, Q1.2 (S), S1.1 (NC1), S1.6 (NO2)
GND: C1.2, C2.2, C3.2 (-), C4.2 (-), C5.2, C6.2, D1.2 (A), D2.2 (A), D4.2 (A), D5.2 (A), J1.A12, J1.B12, J1.MP1, J1.MP2, J1.MP3, J1.MP4, J4.2, J5.2, J6.3, R1.1, R2.1, S1.3 (NO1), S1.4 (NC2)
unnamed: C1.1, C2.1, C3.1 (+), C4.1 (+), D1.1 (K), D2.1 (K), J4.1, J5.1, J6.2, Q1.3 (D)
unnamed: C6.1, FB1.2, J3.3
unnamed: C5.1, D4.1 (K), FB1.1, J1.A9, J1.B9
unnamed: D5.1 (K), J2.1 (SLEEVE), R4.2
unnamed: J1.A5, R1.2
unnamed: J1.B5, R2.2
unnamed: J2.2 (TIP), R5.1
unnamed: C7.1, Q1.1 (G), R3.1, R4.1, TP1.1 (1_1)
unnamed: R5.2, S1.5 (COM2)
unnamed: R3.2, S1.2 (COM_1)

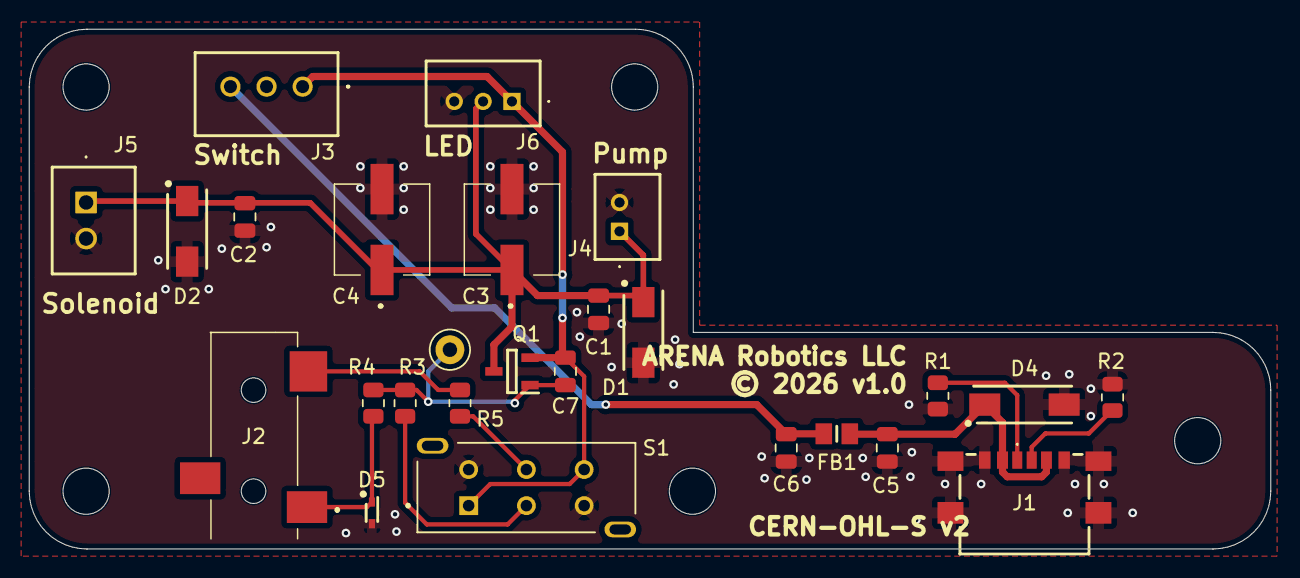
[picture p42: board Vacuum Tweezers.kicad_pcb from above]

Board: 2 copper layers, 86.0 x 36.0 mm, 26 parts (0 on the bottom side), 12 nets.

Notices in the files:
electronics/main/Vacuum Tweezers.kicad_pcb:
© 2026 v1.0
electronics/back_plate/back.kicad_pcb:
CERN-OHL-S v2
